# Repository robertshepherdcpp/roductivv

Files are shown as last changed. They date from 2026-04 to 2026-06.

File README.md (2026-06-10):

# roductivv

**a project to help you regain your time and gain focus!**



**Inspiration/Motivation for building this project**
- i always find myself procrastinating when doing tasks, i know there are apps to do this, but then my phone becomes the distraction and I immediately go onto reels
- so i thought it would be good if i something physical that kept me focused.

**what is this project**
- this project is a tool used to help people become *productive*!
- Gamifies doing tasks like *coding*, *studying* and then punishes activities like *gaming* and *scrolling*!
- This is done via a points based system, where certain activities can earn/loose points.
- Gaining points gets you to different milstones (like 100/250/500/10000) etc..

**how to use**
- first get the pcb and case printed
- then insert the pcb into the case
- add the cherry keys and keycaps
- screw the lid on (using the bolts as shown in the BOM)
- then before flashing to the esp, you need to change the SSID and password in the .ino file to be your own, so that the esp can tell the time (synced with wifi)
- then flash (easiest with the arduino ide), and keeped plugged in and then run!
- there are no batteries, so the connection with the esp must be kept.
- the additional bits on the lid that go down are so that the pcb is fixed in place and doesnt move around

**screenshots of the project**
the 3d design:



the schematic:



the footprint:



**BOM**
- Total cost of this project: $41.12.
- All the costs can be seen in the BOM.csv (in this repository)



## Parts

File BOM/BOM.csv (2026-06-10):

Item | Description | Quantity | Unit Price ($) | Total Price ($) | URL
XIAO ESP32 C3 | MCU | 1 | $4.34 | $4.34 | https://www.aliexpress.us/item/3256808605622611.html
Display | s | 2 | $2.46 | $4.92 | https://www.aliexpress.us/item/3256807544901434.html
Headers | Headers | 1 | $1.57 | $1.57 | https://www.aliexpress.us/item/3256811506646304.html
Buzzer | 12*9.5mm | 1 | $2.23 | $2.23 | https://www.aliexpress.us/item/3256810135642750.html
Threaded Inserts | M3X4X5 | 1 | $2.47 | $2.47 | https://www.aliexpress.us/item/3256811754262338.html
Screws | M3, 16mm | 1 | $2.28 | $2.28 | https://www.aliexpress.com/item/1005005218718202.html?curPageLogUid=A6nTqmv1UyzB
Shipping | Aliexpress | 1 | $0 | $0 | https://www.aliexpress.us/
PCB | JLCPCB | 1 | $6.90 | $6.90 | https://www.jlcpcb.com/
Shipping | JLCPCB | 1 | $3.30 | $3.30 | https://www.jlcpcb.com/
MCP23017 | I/O Expander | 1 | $5.95 | $5.95 | https://www.adafruit.com/product/5346
RGB LED | lights! | 1 | $2.68 | $2.68 | https://www.aliexpress.com/item/1005003327360045.html?curPageLogUid=W3l9LGtACkK0
Resistors | 3x15 ohm | 1 | $0.52 | $0.52 | https://www.aliexpress.com/item/1005006223543783.html?curPageLogUid=TKA6XZl2ZmxR
Cherry MX keys | 1.00u | 1 | $2.05 | $2.05 | https://www.aliexpress.com/item/1005005467023965.html?curPageLogUid=RAE0LX2IZ5Dn
Cherry MX keycaps | - | 1 | $1.91 | $1.91 | https://www.aliexpress.com/item/1005011993806241.html?curPageLogUid=uF0KuedkKbnD
Total | Total cost | - | $41.12 | $41.12 | -

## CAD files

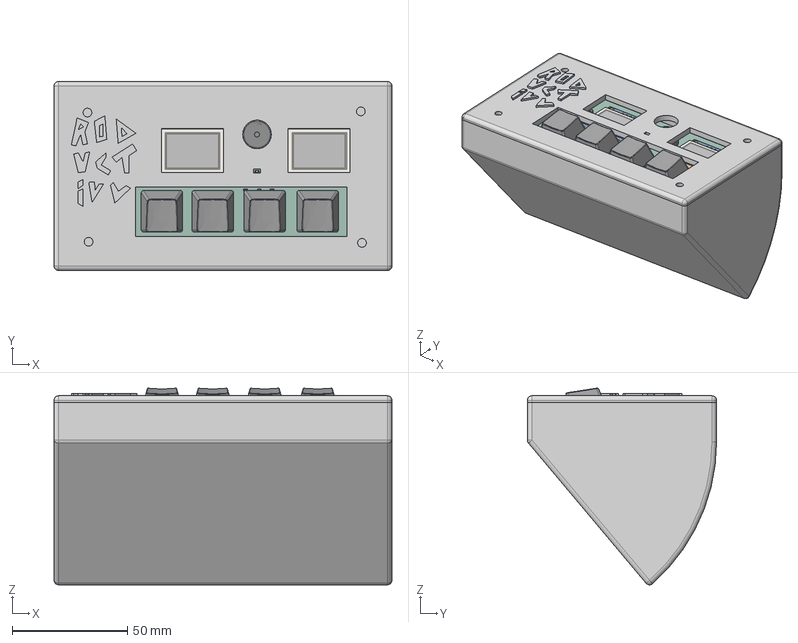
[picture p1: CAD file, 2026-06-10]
CAD/roductivv_v2.step
146.5 x 82.0 x 85.3 mm
BUZ-TH_BD12.5-H7.0-P6.5
R_0603_1608Metric x 3
OLED-TH_L27.8-W27.2-P2.54_C9900033791 x 2
QFN-28-1EP_6x6mm_P0.65mm_EP4.25x4.25mm
LED_0603_1608Metric
roductivv_PCB
BOSS-EXTRUDE14_8_
BOSS-EXTRUDE7_4_
BOSS-EXTRUDE7_3_
BOSS-EXTRUDE14_4_
BOSS-EXTRUDE14_2_
BOSS-EXTRUDE14_11_
BOSS-EXTRUDE7_7_
BOSS-EXTRUDE14_9_
BOSS-EXTRUDE14_3_
BOSS-EXTRUDE14_7_
MIRROR2
BOSS-EXTRUDE14_5_
BOSS-EXTRUDE14_12_
BOSS-EXTRUDE7_8_
BOSS-EXTRUDE7_1_
BOSS-EXTRUDE14_10_
BOSS-EXTRUDE7_9_
BOSS-EXTRUDE14_6_
BOSS-EXTRUDE14_1_
BOSS-EXTRUDE7_6_
BOSS-EXTRUDE7_2_
CUT-EXTRUDE5
BOSS-EXTRUDE7_5_
U.FL Connector v1
Button (1) x 2
Shield
1x1 R1 v23 x 4
1x1 R2 v8 x 4
1x1 R3 v8 x 4
1x1 R4 v6 x 4
1x1.5 R1 v4 x 4
1x1.5 R3 v6 x 4
1x1.5 R4 v5 x 4
1x1.5 R2 v5 x 4
1x1.25 R1 v7 x 4
1x1.25 R2 v4 x 4
1x1.25 R4 v6 x 4
1x1.25 R3 v5 x 4
1x1.75 R1 v6 x 4
1x1.75 R2 v4 x 4
1x1.75 R4 v4 x 4
1x1.75 R3 v5 x 4
1x2 R1 v6 x 4
1x2 R4 v6 x 4
1x2 R3 v6 x 4
1x2 R2 v6 x 4
1x2.25 R1 v6 x 4
1x2.25 R2 v6 x 4
1x2.25 R4 v6 x 4
1x2.25 R3 v6 x 4
1x2.5 R1 v5 x 4
1x2.5 R2 v7 x 4
1x2.5 R3 v6 x 4
1x2.5 R4 v5 x 4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

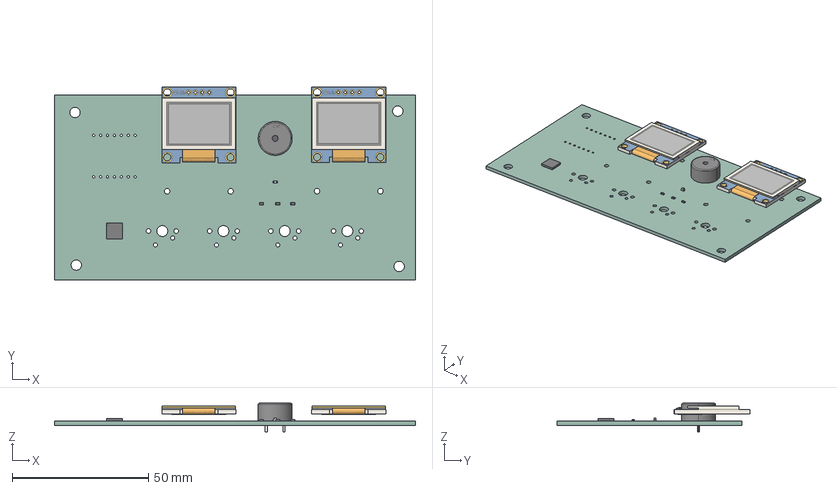
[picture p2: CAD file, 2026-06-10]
PCB/roductivv.step
132.5 x 70.9 x 10.5 mm
BUZ-TH_BD12.5-H7.0-P6.5
R_0603_1608Metric x 3
OLED-TH_L27.8-W27.2-P2.54_C9900033791 x 2
QFN-28-1EP_6x6mm_P0.65mm_EP4.25x4.25mm
LED_0603_1608Metric
roductivv_PCB

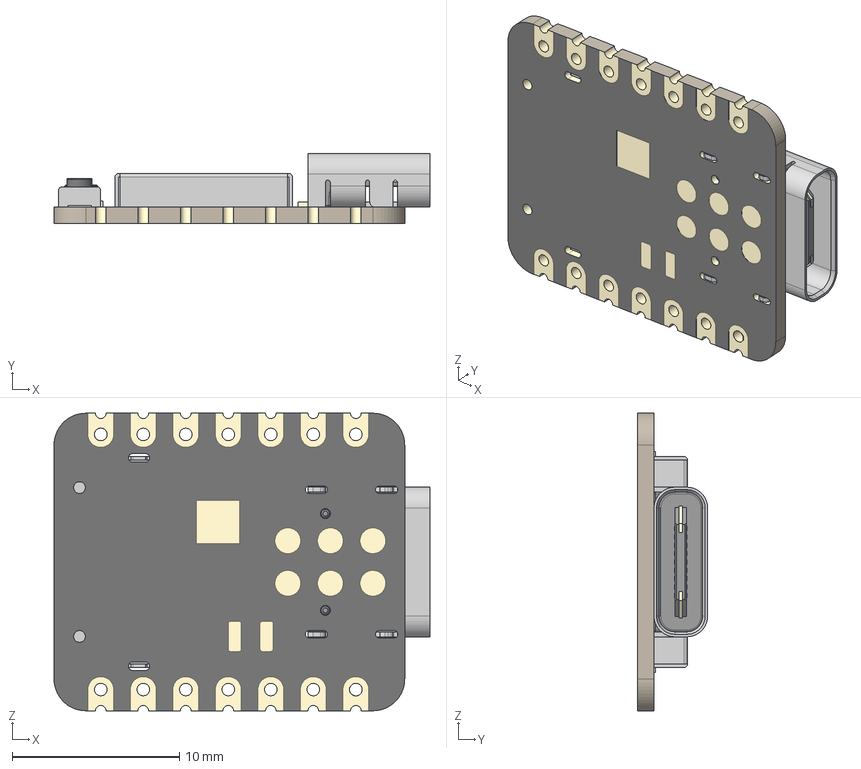
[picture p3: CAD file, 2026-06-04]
CAD/Seeed Studio XIAO-ESP32-C3.step
22.5 x 4.21 x 17.8 mm
BOSS-EXTRUDE14_8_
BOSS-EXTRUDE7_4_
BOSS-EXTRUDE7_3_
BOSS-EXTRUDE14_4_
BOSS-EXTRUDE14_2_
BOSS-EXTRUDE14_11_
BOSS-EXTRUDE7_7_
BOSS-EXTRUDE14_9_
BOSS-EXTRUDE14_3_
BOSS-EXTRUDE14_7_
MIRROR2
BOSS-EXTRUDE14_5_
BOSS-EXTRUDE14_12_
BOSS-EXTRUDE7_8_
BOSS-EXTRUDE7_1_
BOSS-EXTRUDE14_10_
BOSS-EXTRUDE7_9_
BOSS-EXTRUDE14_6_
BOSS-EXTRUDE14_1_
BOSS-EXTRUDE7_6_
BOSS-EXTRUDE7_2_
CUT-EXTRUDE5
BOSS-EXTRUDE7_5_
U.FL Connector v1
Button (1) x 2
Shield

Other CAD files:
CAD/roductivv_v2.f3z

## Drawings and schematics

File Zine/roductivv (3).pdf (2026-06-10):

### with a helpful planner

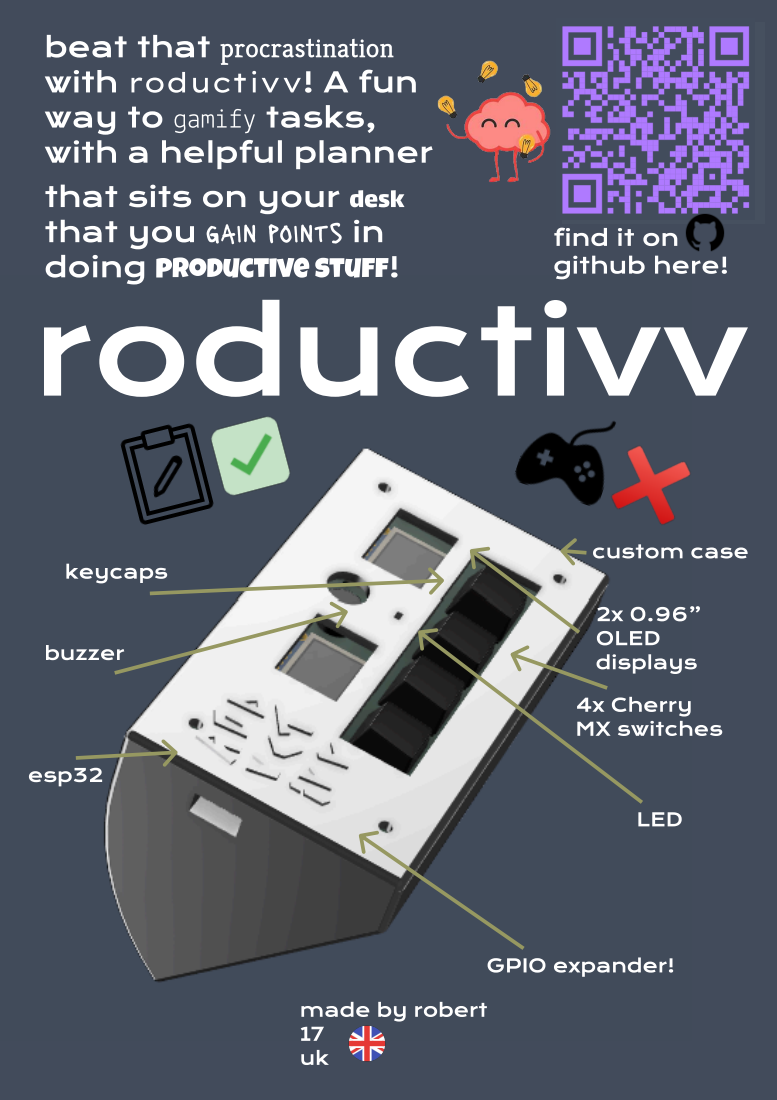
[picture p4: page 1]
esp32; keycaps; buzzer; custom case; 2x 0.96” OLED displays; 4x Cherry; MX switches; LED; GPIO expander!; made by robert

beat that procrastination
with roductivv! A fun
way to gamify tasks,

that sits on your desk
that you gain points in
doing productive stuff!
roductivv

find it on
github here!

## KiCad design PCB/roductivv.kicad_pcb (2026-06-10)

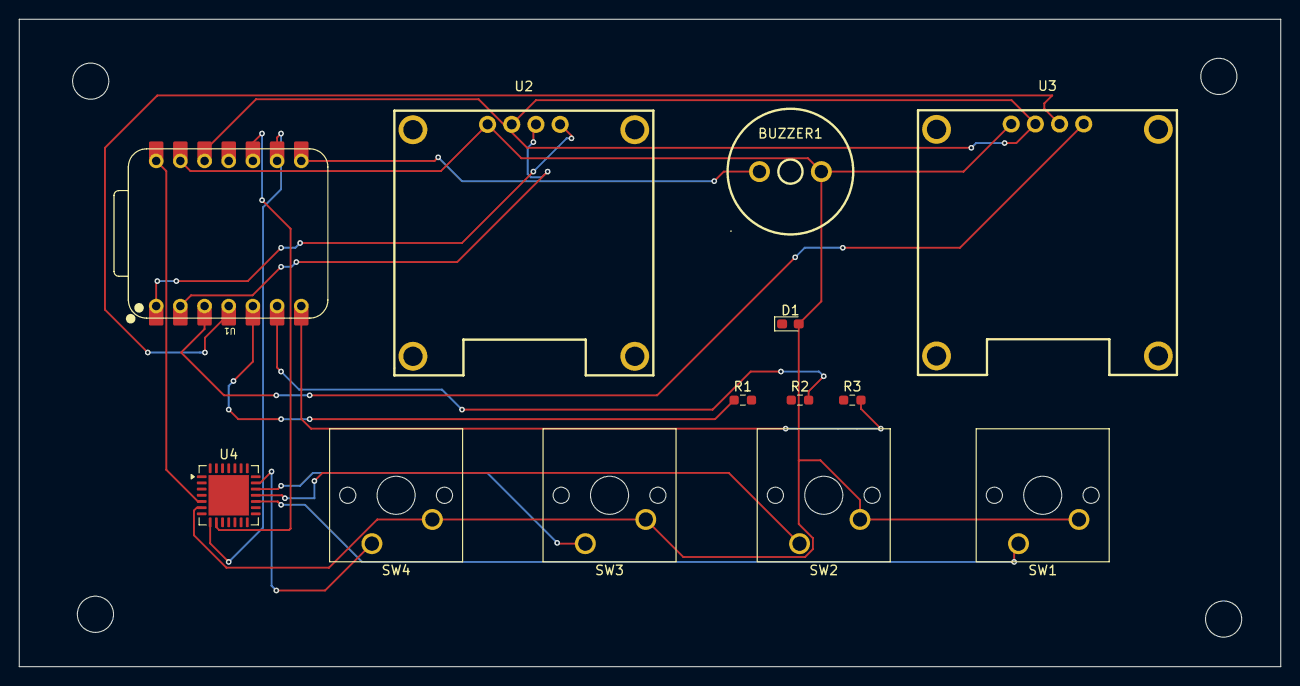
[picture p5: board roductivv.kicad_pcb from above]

Board: 2 copper layers, 132.5 x 68.0 mm, 13 parts (0 on the bottom side), 17 nets.

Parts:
BUZZER1: 1207-P6.5MM; BUZ-TH_BD12.5-P6.50-D1.4
D1: LED_RGB; LED_0603_1608Metric_Pad1.05x0.95mm_HandSolder
R1, R2, R3: 15; R_0603_1608Metric_Pad0.98x0.95mm_HandSolder
SW1, SW2, SW3, SW4: SW_Push; SW_Cherry_MX_1.00u_PCB
U1: XIAO-ESP32-C6-DIP
U2, U3: HS96L03W2C03; OLED-TH_L27.8-W27.2-P2.54_C9900033791
U4: MCP23017_ML; QFN-28-1EP_6x6mm_P0.65mm_EP4.25x4.25mm

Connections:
+3.3V: U1.12 (3V3), U2.2 (VCC), U3.2 (VCC)
+5V: U1.14 (VBUS), U4.5 (VDD)
GND: BUZZER1.2 (-), D1.2 (GK), SW1.2, SW2.2, SW3.2, SW4.2, U1.13 (GND), U2.1 (GND), U3.1 (GND), U4.6 (VSS)
unnamed: BUZZER1.1 (+), U1.8 (GPIO17_D7_RX)
unnamed: U1.1 (GPIO0_A0_D0), U2.4 (SDA)
unnamed: U1.2 (GPIO1_A1_D1), U2.3 (SCL)
unnamed: U1.3 (GPIO2_A2_D2), U3.4 (SDA)
unnamed: R3.2, U1.7 (GPIO16_D6_TX)
unnamed: U1.9 (GPIO19_D8_SCK), U4.8 (SCK)
unnamed: U1.10 (GPIO20_D9_MISO), U4.9 (SDA)
unnamed: U1.4 (GPIO21_D3), U3.3 (SCL)
unnamed: R1.1, U1.5 (GPIO22_D4_SDA)
unnamed: R2.2, U1.6 (GPIO23_D5_SCL)
unnamed: SW1.1, U4.17 (GPA0)
unnamed: SW2.1, U4.18 (GPA1)
unnamed: SW3.1, U4.19 (GPA2)
unnamed: SW4.1, U4.20 (GPA3)

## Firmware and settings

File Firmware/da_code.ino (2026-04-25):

#include "Adafruit_MCP23X17.h"
#include <Wire.h>
#include <Adafruit_GFX.h>
#include <Adafruit_SSD1306.h>
#include <Preferences.h>

// for wifi communcation: to handle time.
#include <WiFi.h>
#include <NTPClient.h>
#include <WiFiUdp.h>

// TODO: replace these with actual stuff
const char* ssid     = "REPLACE_WITH_YOUR_SSID";
const char* password = "REPLACE_WITH_YOUR_PASSWORD";

WiFiUDP ntpUDP;
NTPClient timeClient(ntpUDP);

// Variables to save date and time
String formattedDate;
String dayStamp;
String timeStamp;

Preferences preferences;

#define SCREEN_WIDTH 128
#define SCREEN_HEIGHT 64
#define OLED_RESET -1

TwoWire wire0 = TwoWire(0);
TwoWire wire1 = TwoWire(1);

Adafruit_SSD1306 display1(SCREEN_WIDTH, SCREEN_HEIGHT, &wire0, OLED_RESET); // display 1
Adafruit_SSD1306 display2(SCREEN_WIDTH, SCREEN_HEIGHT, &wire1, OLED_RESET); // display 2

// PORTS ON THE MCP23017
// buttons
#define BTN_1 0
#define BTN_2 1
#define BTN_3 2
#define BTN_4 3

// PORTS ON THE ESP

// the GPIO extender
#define MCP23017SCK 19
#define MCP23017SDA 20

// buzzer
#define BZR 17

// leds
#define LED1 22
#define LED2 23
#define LED3 16

// screen 1
#define SDA1_PIN 0
#define SCL1_PIN 1

// screen 2
#define SDA2_PIN 2
#define SCL2_PIN 21

Adafruit_MCP23X17 mcp;

enum class STATES {
  STUDYING,
  CODING,
  SCROLLING,
  GAMING,
  OPTIONS
};

STATES cur_state = STATES::OPTIONS;

int timer = 0;

int scroll_count = 0;
int gaming_count = 0;
int score = 0;
// int time_elapsed = 0;
bool started = false;
int last_timer_update = 0;

// 100; 250; 500; 1,000; 5,000; 10,000, 100,000, 1,000,000
bool milestones[8] = {0, 0, 0, 0, 0, 0, 0, 0};

const unsigned char PROGMEM spriteOPTION[] = {
  0b00000000, 0b00000000,
  0b00001111, 0b11000000,
  0b00011000, 0b01100000,
  0b00010000, 0b00100000,
  0b00000000, 0b00100000,
  0b00000000, 0b00100000,
  0b00000000, 0b01100000,
  0b00000001, 0b11000000,
  0b00000001, 0b00000000,
  0b00000001, 0b00000000,
  0b00000001, 0b00000000,
  0b00000000, 0b00000000,
  0b00000001, 0b00000000,
  0b00000000, 0b00000000,
  0b00000000, 0b00000000,
  0b00000000, 0b00000000
};

const unsigned char PROGMEM spriteCODING[] = {
  0b00000000, 0b00000000,
  0b00000000, 0b00000000,
  0b00000011, 0b00000000,
  0b00000110, 0b00000010,
  0b00001100, 0b00000110,
  0b00001000, 0b10001100,
  0b00001000, 0b00001000,
  0b00010000, 0b00001000,
  0b00010000, 0b10001000,
  0b00011000, 0b00011000,
  0b00001100, 0b00011000,
  0b00000111, 0b10011000,
  0b00000000, 0b11010000,
  0b00000000, 0b00000000,
  0b00000000, 0b00000000,
  0b00000000, 0b00000000
};

const unsigned char PROGMEM spriteSTUDYING[] = {
  0b00000000, 0b00000000,
  0b00000000, 0b00000000,
  0b00000000, 0b00000000,
  0b00000000, 0b00000000,
  0b00000000, 0b11100000,
  0b00000000, 0b10011000,
  0b00000001, 0b00001100,
  0b00000010, 0b00000110,
  0b00000110, 0b00001110,
  0b00000100, 0b00001110,
  0b00001000, 0b00001110,
  0b00001110, 0b00011110,
  0b00001111, 0b10111110,
  0b00001111, 0b11111110,
  0b00001111, 0b11111100,
  0b00000111, 0b11111000
};

const unsigned char PROGMEM spriteSCROLLING[] = {
  0b00000000, 0b00000000,
  0b00000000, 0b00000000,
  0b00001100, 0b00010000,
  0b00001111, 0b00111000,
  0b00011111, 0b01111000,
  0b00001111, 0b11111000,
  0b00000111, 0b11110000,
  0b00000011, 0b11100000,
  0b00000011, 0b11111000,
  0b00000111, 0b11111100,
  0b00001111, 0b11111110,
  0b00001111, 0b01111110,
  0b00001110, 0b00111100,
  0b00001100, 0b00001100,
  0b00000000, 0b00000000,
  0b00000000, 0b00000000
};

const unsigned char PROGMEM spriteGAMING[] = {
  0b00000000, 0b00000000,
  0b00000000, 0b00000000,
  0b00000000, 0b00000000,
  0b00000000, 0b00000000,
  0b00000000, 0b00000000,
  0b00000000, 0b00000000,
  0b00011111, 0b11111000,
  0b00010000, 0b00001100,
  0b00110110, 0b01100100,
  0b00100110, 0b01100010,
  0b00100000, 0b00000110,
  0b00111111, 0b11111100,
  0b00000000, 0b00000000,
  0b00000000, 0b00000000,
  0b00000000, 0b00000000,
  0b00000000, 0b00000000
};

// Usage:
// display.drawBitmap(x, y, sprite, 16, 16, SSD1306_WHITE);

// the tunes for the different milstones, with a starting note of varying durations.
void play100() {
  tone(BZR, 1500, 100);
  delay(300);
  tone(BZR, 1000, 50);
  delay(300);
  tone(BZR, 1000, 50);
  delay(300);
  tone(BZR, 1000, 50);
}
void play250() {
  tone(BZR, 1500, 150);
  delay(300);
  tone(BZR, 1000, 50);
  delay(300);
  tone(BZR, 1000, 50);
  delay(300);
  tone(BZR, 1000, 50);
}
void play500() {
  tone(BZR, 1500, 200);
  delay(300);
  tone(BZR, 1000, 50);
  delay(300);
  tone(BZR, 1000, 50);
  delay(300);
  tone(BZR, 1000, 50);
}
void play1000() {
  tone(BZR, 1500, 250);
  delay(300);
  tone(BZR, 1000, 50);
  delay(300);
  tone(BZR, 1000, 50);
  delay(300);
  tone(BZR, 1000, 50);
}
void play5000() {
  tone(BZR, 1500, 300);
  delay(300);
  tone(BZR, 1000, 50);
  delay(300);
  tone(BZR, 1000, 50);
  delay(300);
  tone(BZR, 1000, 50);
}
void play10000() {
  tone(BZR, 1500, 400);
  delay(300);
  tone(BZR, 1000, 50);
  delay(300);
  tone(BZR, 1000, 50);
  delay(300);
  tone(BZR, 1000, 50);
}
void play100000() {
  tone(BZR, 1500, 500);
  delay(300);
  tone(BZR, 1000, 50);
  delay(300);
  tone(BZR, 1000, 50);
  delay(300);
  tone(BZR, 1000, 50);
}
void play1000000() {
  tone(BZR, 1500, 1000);
  delay(300);
  tone(BZR, 1000, 50);
  delay(300);
  tone(BZR, 1000, 50);
  delay(300);
  tone(BZR, 1000, 50);
}

// getting all the different components ready.
void setup() {
  // get the values for amount of time
  preferences.begin("my-app", false);
  scroll_count = preferences.getInt("scrolls", 0);
  gaming_count = preferences.getInt("games", 0);
  preferences.end();

  // connect to the wifi for date and time
  WiFi.begin(ssid, password);
  while (WiFi.status() != WL_CONNECTED) {
    delay(500);
    Serial.print(".");
  }
  timeClient.begin();
  timeClient.setTimeOffset(0);

  // the gpio expander
  if (!mcp.begin_I2C()) {
    Serial.println("Error.");
    while (1);
  }

  mcp.pinMode(BTN_1, INPUT_PULLUP);
  mcp.pinMode(BTN_2, INPUT_PULLUP);
  mcp.pinMode(BTN_2, INPUT_PULLUP);
  mcp.pinMode(BTN_3, INPUT_PULLUP);

  // the screen.
  wire0.begin(SDA1_PIN, SCL1_PIN);
  wire1.begin(SDA2_PIN, SCL2_PIN);

  display1.begin(SSD1306_SWITCHCAPVCC, 0x3C);
  display2.begin(SSD1306_SWITCHCAPVCC, 0x3C);

  // buzzer.
  pinMode(BZR, OUTPUT);

  // the LED
  pinMode(LED1, OUTPUT);
  pinMode(LED2, OUTPUT);
  pinMode(LED3, OUTPUT);

}

auto checkButtons() {
  if (!mcp.digitalRead(BTN_1)) {
    if(cur_state != STATES::STUDYING && timer > 0) {
      // cant change unless have completed the time. COULD CHANGE THIS LATER SO THAT IF WAS SCROLLING/GAMING CAN SWITCH.
      Serial.print("got to finish already allocated time first!");
    } else {
      cur_state = STATES::STUDYING;
      timer += 10 * 60; // add 10 minutes to the timer
    }
  } else if(!mcp.digitalRead(BTN_2)) {
    if(cur_state != STATES::CODING && timer > 0) {
      // cant change unless have completed the time. COULD CHANGE THIS LATER SO THAT IF WAS SCROLLING/GAMING CAN SWITCH.
      Serial.print("got to finish already allocated time first!");
    } else {
      cur_state = STATES::CODING;
      timer += 10 * 60; // add 10 minutes to the timer
    }
  } else if(!mcp.digitalRead(BTN_3)) {
    if(cur_state != STATES::SCROLLING && timer > 0) {
      // cant change unless have completed the time. COULD CHANGE THIS LATER SO THAT IF WAS SCROLLING/GAMING CAN SWITCH.
      Serial.print("got to finish already allocated time first!");
    } else if(cur_state == STATES::SCROLLING || scroll_count > 0) {
      // cant do more reels after 10 minutes!
      Serial.print("cant scroll for more than 10 minutes!");
    } else {
      cur_state = STATES::SCROLLING;
      timer += 10 * 60; // add 10 minutes to the timer
      scroll_count += 1;
      preferences.begin("my-app", false);
      preferences.putInt("scrolls", scroll_count);
      preferences.putString("lastScroll", dayStamp);
      preferences.end();
    }
  } else if(!mcp.digitalRead(BTN_4)) {
    if(cur_state != STATES::GAMING && timer > 0) {
      // cant change unless have completed the time. COULD CHANGE THIS LATER SO THAT IF WAS SCROLLING/GAMING CAN SWITCH.
      Serial.print("got to finish already allocated time first!");
    } else if(cur_state == STATES::GAMING || gaming_count > 2) {
      // cant do more reels after 10 minutes!
      Serial.print("cant scroll for more than 10 minutes!");
    } else {
      cur_state = STATES::GAMING;
      timer += 10 * 60; // add 10 minutes to the timer
      gaming_count += 1;
      preferences.begin("my-app", false);
      preferences.putInt("games", gaming_count);
      preferences.putString("lastGame", dayStamp);
      preferences.end();
    }
  }
}

auto updateAndLogic() {
  // time synced with the wifi...
  while(!timeClient.update()) {
    timeClient.forceUpdate();
  }
  // string manip :()
  formattedDate = timeClient.getFormattedDate();
  int splitT = formattedDate.indexOf("T");
  dayStamp = formattedDate.substring(0, splitT);
  timeStamp = formattedDate.substring(splitT+1, formattedDate.length()-1);
  delay(1000);
  auto idx_1 = formattedDate.indexOf(":");
  String hours_ = formattedDate.substring(0, idx_1);
  String rest = formattedDate.substring(idx_1+1, formattedDate.length()-1);
  auto idx_2 = rest.indexOf(":");
  String minutes_ = rest.substring(0, idx_2);
  String seconds_ = rest.substring(idx_2+1, rest.length()-1);
  int hours = hours_.toInt();
  int minutes = minutes_.toInt();
  int seconds = seconds_.toInt();

  int seconds_elapsed_today = hours * 60 * 60 + minutes * 60 + seconds;
  if(!started) {
    int seconds_started = seconds_elapsed_today;
    started = true;
    last_timer_update = seconds_elapsed_today;
  }

  // if the day stamp has changed, then we reset scroll_count and gaming_count to 0
  preferences.begin("my-app", false);
  String scroll = preferences.getString("lastScroll", dayStamp);
  String game = preferences.getString("lastGame", dayStamp);

  preferences.end();

  // this ensures the games/scrolls gets reset after each day.
  if(scroll != dayStamp) {
    scroll_count = 0;
  }
  if (game != dayStamp) {
    gaming_count = 0;
  }


  // for now im just going to use delay, there is going to be a better way..
  if(timer > 0) {
    //delay(1000);
    //time_elapsed += 1;
    // we reset limits after one day, however this requires it being plugged in, storing is too complicated as have to know the date and everything...
    // if(time_elapsed >= 24 * 60 * 60) {
    // }
    if(timer == 1) {
      // the we have finished the 10 minutes, do a buzzer sound!
      tone(BZR, 1000, 100);
      cur_state = STATES::OPTIONS;
    }
    if(timer % (10*60) == 1) {
    // depending on the acitvity we will add/deduct points, as will have finished another 10 minutes
      switch(cur_state) {
        case STATES::STUDYING:
          score += 10;
          break;
        case STATES::CODING:
          score += 15;
          break;
        case STATES::SCROLLING:
          score -= 20;
          break;
        case STATES::GAMING:
          score -= 5;
          break;
      }
    }
    timer -= seconds_elapsed_today - last_timer_update; // we calculate the difference, we dont just do delay(1000); more accurate here, but may
                                                        // not do even count down with the timer display
    last_timer_update = seconds_elapsed_today;
  }
  // now check for highscores
  if(score >= 100 && milestones[0] == 0) {
    play100();
    milestones[0] = 1;
  }
  if(score >= 250 && milestones[1] == 0) {
    play250();
    milestones[1] = 1;
  }
  if(score >= 500 && milestones[2] == 0) {
    play500();
    milestones[2] = 1;
  }
  if(score >= 1000 && milestones[3] == 0) {
    play1000();
    milestones[3] = 1;
  }
  if(score >= 5000 && milestones[4] == 0) {
    play5000();
    milestones[4] = 1;
  }
  if(score >= 10000 && milestones[5] == 0) {
    play10000();
    milestones[5] = 1;
  }
  if(score >= 100000 && milestones[6] == 0) {
    play100000();
    milestones[6] = 1;
  }
  if(score >= 100000 && milestones[7] == 0) {
    play100000();
    milestones[7] = 1;
  }

  // update the LED.
  switch(cur_state) {
    case STATES::STUDYING:
      digitalWrite(LED1, HIGH);
      break;
    case STATES::CODING:
      digitalWrite(LED2, HIGH);
      break;
    case STATES::SCROLLING:
      digitalWrite(LED3, HIGH);
      break;
    case STATES::GAMING:
      digitalWrite(LED1, HIGH);
      digitalWrite(LED2, HIGH);
      //digitalWrite(LED3, HIGH);
      break;
    case STATES::OPTIONS:
      digitalWrite(LED1, HIGH);
      digitalWrite(LED2, HIGH);
      digitalWrite(LED3, HIGH);

  }
}


// TODO: MAKE IT MORE AESTHETICALLY PLEASING.
auto render() {
  // we have to render things on both screens.
  // first deal with the first screen. (the options) and the stats (the stats will show no matter the screen state.)
  display1.clearDisplay();
  const unsigned char* bitmap;
  switch(cur_state) {
    case STATES::OPTIONS:
      display1.setCursor(0, 56);
      display1.setTextSize(1);
      display1.println("[STUDY] [CODE] [SCRL] [GME]");
      bitmap = spriteOPTION;
      break;
    case STATES::STUDYING:
      display1.setCursor(0, 56);
      display1.setTextSize(2);
      display1.println("STUDYING");
      bitmap = spriteSTUDYING;
      break;
    case STATES::CODING:
      display1.setCursor(0, 56);
      display1.setTextSize(2);
      display1.println("CODING");
      bitmap = spriteCODING;
      break;
    case STATES::SCROLLING:
      display1.setCursor(0, 56);
      display1.setTextSize(2);
      display1.println("SCROLLING");
      bitmap = spriteSCROLLING;
      break;
    case STATES::GAMING:
      display1.setCursor(0, 56);
      display1.setTextSize(2);
      display1.println("GAMING");
      bitmap = spriteGAMING;
      break;
  }

  // draw the bitmap
  display1.drawBitmap(56, 2, bitmap, 16, 16, SSD1306_WHITE);

  // then all will display that stats
  display1.setCursor(0, 24);
  display1.setTextSize(1);
  display1.println("CURRENT POINTS: ");
  display1.setCursor(50, 24);
  display1.println(score);

  display1.display();

  // now the second screen, the timer.
  display2.clearDisplay();

  display2.setCursor(0, 30);
  display2.setTextSize(2);
  display2.println("TIME: ");
  display2.setCursor(50, 30);
  int minutes = (timer - (timer % 60)) / 60;
  int seconds = timer - (minutes * 60);
  display2.println(minutes);
  display2.setCursor(60, 30);
  display2.println(":");
  display2.setCursor(65, 30);
  display2.println(seconds);

  display2.display();
}

// auto handleScreenLogic() {
//   // here we need to deal with 2 screens!
// }

void loop() {
  checkButtons(); // check inputs
  updateAndLogic(); // update all stuff, check for new milstones and change time etc.
  // handleScreenLogic();  // 3. Process actions
  render(); // draw on screen
  // dont think we need it? however could reduce our version of counting down to 900ms from 1000ms.
  //delay(100);           // 5. Short pause
}

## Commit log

2026-04-20 add pcb files
    [roductivv.kicad_pcb, roductivv.kicad_sch]
2026-04-24 Add BOM.csv with item details and pricing
    [BOM.csv]
2026-04-24 Update README with project cost information
    Added cost details and BOM reference to README.
2026-04-24 Change MCP23017 price and supplier
    Updated MCP23017 price and source link.
    [BOM.csv]
2026-04-24 Update README with usage instructions and assembly steps
    Added usage instructions for the project, including assembly steps and firmware setup.
2026-04-25 Add RGB LED entry to BOM
    [BOM.csv]
2026-04-25 Add resistors entry to BOM.csv
    [BOM.csv]
2026-04-25 add gerber files
2026-04-25 try add it again
    [roductivv.step]
2026-04-28 Update README to remove wheels description
    Removed description of wheels from design considerations.
2026-04-28 Fix wording in README about project case
    Removed redundant wording about the case on wheels in the README.
2026-04-28 add the case file
    [roductivv.f3d]
2026-05-08 add the step file for the project.
    [roductivv.step]
2026-05-08 Revise README with project details and BOM
    Updated project description and added BOM section.
2026-05-08 Update BOM.csv with new items
    Added new items 'Cherry MX keys' and 'Cherry MX keycaps' to BOM.
    [BOM.csv]
2026-05-08 Fix formatting for Cherry MX keys and keycaps entries
    [BOM.csv]
2026-06-04 add the microcontroller cad file
    [Seeed Studio XIAO-ESP32-C3.step]
2026-06-04 Clarify lid design purpose in README
    Added clarification about the lid's additional bits for PCB stability.
2026-06-10 Update BOM.csv with new component details
    [BOM.csv]
2026-06-10 add the new gerber files.
2026-06-10 add the updated pcb editor screenshot.
2026-06-10 add updated pcb files.
    [roductivv.kicad_pcb, roductivv.kicad_sch]
2026-06-10 add the pcb 3d model
    [roductivv.step]
2026-06-10 add the updated step file.
    [roductivv_v2.step]
2026-06-10 add the updated fusion file.
    [roductivv_v2.f3z]
